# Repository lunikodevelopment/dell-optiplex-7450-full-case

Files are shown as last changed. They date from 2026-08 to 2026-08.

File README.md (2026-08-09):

# Dell OptiPlex 7450 AIO Full Enclosure — V3.1 Clearance-First

> [!IMPORTANT]
> **AI-authorship disclosure:** This CAD project and its documentation were generated with **OpenAI ChatGPT (GPT-5.6 Sol)** from Dell specifications, user-supplied photographs, independent product photographs, and iterative requirements. The CAD source, exported geometry, QA scripts/results, and engineering recommendations are AI-generated. This is **not a certified engineering product** and has not been physically validated on every Dell OptiPlex 7450 AIO.

V3.1 is the **pre-purchase / clearance-first** revision. It intentionally gives up a small amount of cosmetic tightness to remove dependence on unpublished Dell dimensions while retaining the full enclosure concept, wall mounting, H2C compatibility, and efficient SLS/MJF production.

## What changed from V3

- Dell receiver reduced from **138 × 138 mm to 128 × 128 mm**.
- Receiver remains **10 mm structurally thick** with 6 mm Dell-side standoffs.
- VESA remains the official **100 × 100 mm M4** pattern.
- Steel wall-stud/keyhole pattern widened to **84 × 56 mm**.
- Bottom-center receiver opening widened to **56 mm** and extended to the edge so the stand latch/mechanism is not trapped behind a flat plate.
- Positive anti-lift geometry corrected: seated clearance is **1.0 mm**, with no block/ear intersection, while only 1 mm of lift is available before the lock stops motion versus 14 mm required to release the keyholes.
- Enclosure body clearance increased to **5 mm per side** (10 mm total X/Y).
- Rear/depth clearance increased to **8 mm** beyond Dell's maximum published chassis depth.
- Front retention overlap reduced to **2 mm** per edge.
- Central shell exclusion increased to **190 × 190 mm**.
- Side I/O, optical-drive/control, rear-port and top-exhaust regions remain broadly open instead of depending on guessed port coordinates.
- All H2C parts remain inside the conservative **300 × 315 × 315 mm** design envelope; largest generated H2C part is about **295.62 × 210.45 × 74.3 mm**.

## Published Dell basis

- Chassis: **575.24 × 392.90 × 63.50 mm maximum published depth**.
- VESA: **FDMI MIS-D 100 × 100 mm, M4**.
- Minimum wall clearance: **20 mm**.
- V3.1 nominal Dell-rear-to-wall distance: **52.3 mm**.
- V3.1 nominal printed-shell-to-wall clearance: **41.5 mm**.

## Photo-derived rear-bay cross-check

The supplied near-orthogonal rear photograph contains the same four VESA threaded centers whose spacing is independently published as 100 mm. Using that known spacing as an image scale gives an approximate visible stand bay of **145.5–149.3 mm wide** and about **150.9 mm high**.

This is not metrology-grade because of perspective and edge ambiguity, but it gives the 128 mm receiver roughly **8.7–10.7 mm lateral clearance per side** and roughly **11.5 mm top/bottom clearance** against the visible bay boundary. The new 56 mm open-bottom notch additionally avoids the prominent stand latch visible below the lower M4 pair.

Independent rear photographs and genuine Dell 7450VESA bracket photographs corroborate the same bay/latch/bracket arrangement, although no dimensioned engineering drawing of the exterior recess or usable M4 thread depth was found. See `ONLINE_SOURCE_NOTES.md` and `REVALIDATION_V3_1.md`.

## Repository layout

Current source/build files:

- `source_parts_v3_1/` — chunked canonical V3.1 CadQuery source used by CI.
- `build_v3_1.py` — reconstructs `CAD_SOURCE_make_v3_1.py` and builds the CAD.
- `CAD_SOURCE_make_v3_1.py` — generated complete source file after CI runs.
- `.github/workflows/generate-cad.yml` — automatically regenerates production files.

Generated production files are committed under `generated/`:

- `generated/sls_mjf/` — **2 rear halves + 2 front halves** for large-format SLS/MJF PA12.
- `generated/h2c/` — **4 rear quadrants + 4 front quadrants** for H2C-class FDM.
- `generated/universal/` — structural receiver, wall plate, anti-lift block and seam joiners.
- `generated/fit_checks/` — inexpensive validation templates/coupons.
- `generated/optional_metal/` — optional 2 mm receiver backer in STL/STEP/DXF form.
- `generated/case_reference_assembly.step` — enclosure reference assembly.
- `generated/wall_interface_entry.step` / `generated/wall_interface_seated.step` — wall-interface kinematic references.

## Manufacturing paths

### H2C / large-format FDM

Use the `generated/h2c/` set. The enclosure quadrants are sized to stay under a conservative 300 × 315 × 315 mm envelope. A single nozzle/material is sufficient. See `H2C_PRINT_PLAN.md`.

### SLS / MJF

Use the `generated/sls_mjf/` set for the lowest assembly count: two rear shell halves and two front-retainer halves. PA12 or comparable functional nylon is preferred. See `SLS_MJF_PLAN.md`.

## Structural system

The printed enclosure is deliberately **not the primary wall-load path**. The Dell's VESA connection transfers through the 128 × 128 × 10 mm receiver to four steel M8 studs and the wall plate.

The receiver includes:

- 100 × 100 mm M4 Dell interface;
- approximately 20 mm OD fender-washer bearing areas;
- 84 × 56 mm four-stud pattern;
- 14 mm gravity seating travel;
- broad open-bottom latch relief;
- removable positive anti-lift block secured by an M5 fastener.

For a permanent installation, the optional 2 mm metal receiver backer or a commercial metal VESA backbone is strongly preferred.

## Fit checks

The design is intentionally much less dependent on unpublished Dell geometry, but the repository still includes cheap validation parts:

1. `generated/fit_checks/vesa_recess_fit_template_2p5mm.stl`
2. `generated/fit_checks/m8_keyhole_and_insert_coupon.stl`
3. `generated/fit_checks/enclosure_corner_depth_coupon.stl`
4. `generated/fit_checks/enclosure_front_corner_coupon.stl`
5. `generated/fit_checks/front_overlap_1_2_3mm_coupon.stl`
6. `generated/fit_checks/wall_drill_template_2mm.stl`

The **M4 screw length / usable thread depth remains unpublished**. Do not choose final screw length solely from this model.

## QA status

See `QA_RESULTS.json` and `REVALIDATION_V3_1.md`.

Current generated V3.1 checks include:

- receiver outline ≤140 mm: PASS;
- structural receiver thickness 9–10 mm: PASS;
- nominal shell-to-wall clearance ≥20 mm: PASS;
- wall/receiver collision in seated state: **0 mm³**;
- wall/receiver collision in entry state: **0 mm³**;
- positive lock collision-free when seated: PASS;
- lock prevents lift-off before 14 mm keyhole release travel: PASS;
- all exported STL meshes watertight: PASS;
- all H2C production parts inside the conservative envelope: PASS.

These are CAD/mesh checks, not certification of wall substrate, fasteners, printed-material strength, creep life, thermal behavior, or manufacturing variation in a used AIO.

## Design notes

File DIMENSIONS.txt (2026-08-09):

Dell OptiPlex 7450 AIO V3.1 design basis

Published Dell chassis envelope used: 575.24 x 392.90 x 63.50 mm max depth
Published VESA pattern: 100 x 100 mm, M4
Published minimum wall clearance: 20 mm

V3.1 receiver: 128 x 128 mm, 10 mm structural thickness + 6 mm Dell-side standoffs
M8 stud pattern: 84 x 56 mm
Keyhole seating travel: 14 mm
Central shell exclusion: 190 x 190 mm
Nominal internal X/Y clearance: 10 mm total (5 mm each side)
Extra depth clearance: 8 mm
Front overlap: 2 mm
Enclosure outer reference envelope: 591.24 x 408.90 x 74.30 mm
Nominal Dell rear to wall: 52.3 mm
Nominal shell to wall: 41.5 mm
H2C conservative part envelope: 300 x 315 x 315 mm
Largest H2C part: 295.62 x 210.45 x 74.30 mm

Approximate photo-derived visible stand bay: 145.5–149.3 mm wide x ~150.9 mm high. This is a photographic cross-check, not a dimensioned Dell specification.

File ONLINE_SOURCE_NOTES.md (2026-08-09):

# Online source notes — V3.1

Sources used to establish the design basis and cross-check the clearance-first revision:

1. **Dell OptiPlex 7450 AIO Owner's Manual — VESA wall mount**: confirms 100 × 100 mm VESA, M4 screws and a minimum 20 mm wall clearance.
2. **Dell OptiPlex 7450 AIO Owner's Manual — physical specifications**: confirms 575.24 mm width, 392.90 mm height, 63.5 mm non-touch depth / 62.79 mm touch depth.
3. **Dell OptiPlex 7450 AIO visual guide / service documentation**: confirms stand removal and the general external I/O, control and ventilation regions.
4. **Independent used-system rear photographs**: corroborate the square recessed stand bay and bottom-center latch arrangement after the stand is removed.
5. **Genuine Dell 7450VESA replacement-bracket photographs**: corroborate the internal VESA bracket arrangement.
6. **Bambu Lab H2C product documentation**: used only as an external printer-size cross-check; V3.1 nevertheless constrains its H2C parts to a conservative 300 × 315 × 315 mm design envelope.

No online source located during the V3.1 research provided a dimensioned engineering drawing of the exterior stand recess, exact rear curvature, or usable M4 thread depth. The receiver was therefore reduced to 128 × 128 mm, given an open-bottom latch relief, and combined with larger enclosure clearances so those unpublished dimensions are not required for nominal fit.

The photo-derived rear-bay figures in the README and revalidation report use the independently known 100 mm VESA spacing as an image scale. They are corroborative estimates rather than factory tolerances.

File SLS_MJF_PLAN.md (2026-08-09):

# SLS / MJF Plan — V3.1

Preferred material: **PA12 or comparable functional nylon**.

Production set:
- rear_left_half
- rear_right_half
- front_left_half
- front_right_half
- universal receiver/wall hardware as separate parts

The shell is thin-wall/open-frame geometry intended to avoid unnecessary solid material. Powder-bed production removes FDM support constraints. The service must confirm that the full-height half-shell parts fit its machine envelope and quotation rules.

For permanent wall mounting, keep the printed shell nonstructural and use the optional metal backer or a commercial metal VESA backbone.

The production set is generated under `generated/sls_mjf/` by the repository workflow.

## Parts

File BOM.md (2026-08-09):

# V3.1 hardware BOM

Structural interface:
- 4 × M4 Dell VESA screws — usable thread depth / final screw length remains unit-specific
- 4 × M4 fender washers, about 20 mm OD
- 4 × M8 steel carriage bolts / equivalent studs
- 4 × M8 large washers
- 4 × M8 locking nuts / thin jam nuts as required by the actual stud-head stack
- 1 × M5 socket-head screw for the positive anti-lift block
- 1 × M5 square nut for the receiver pocket
- optional 2 mm aluminum receiver backer
- optional secondary steel tether

Enclosure:
- M3 screws, washers and nyloc nuts for rear seam joiners
- 8 × M3 threaded inserts (or service-selected equivalent) for front retainer tabs
- 8 × M3 front-retainer screws

Wall:
- fasteners/anchors selected for the actual wall substrate; the CAD defines hole layout, not substrate-specific anchor selection.

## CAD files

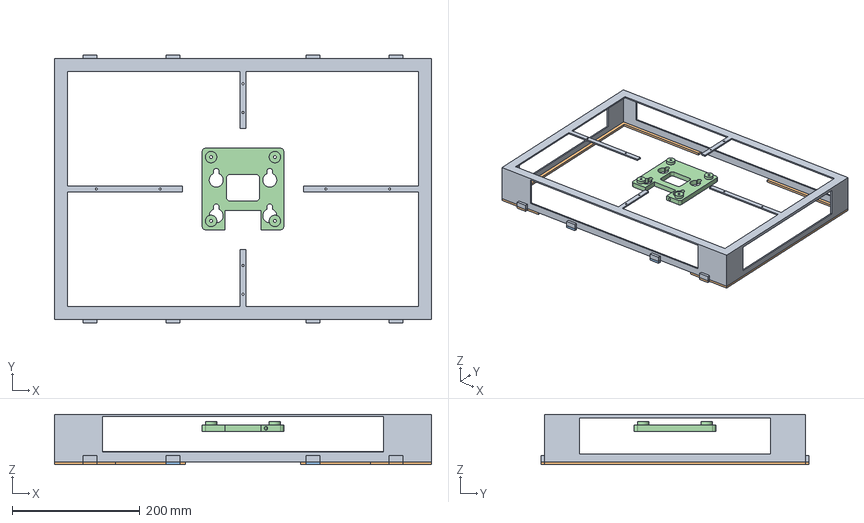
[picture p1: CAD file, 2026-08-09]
generated/case_reference_assembly.step
591.2 x 420.9 x 78.8 mm
rear_shell
front_retainer
vesa_receiver_reference

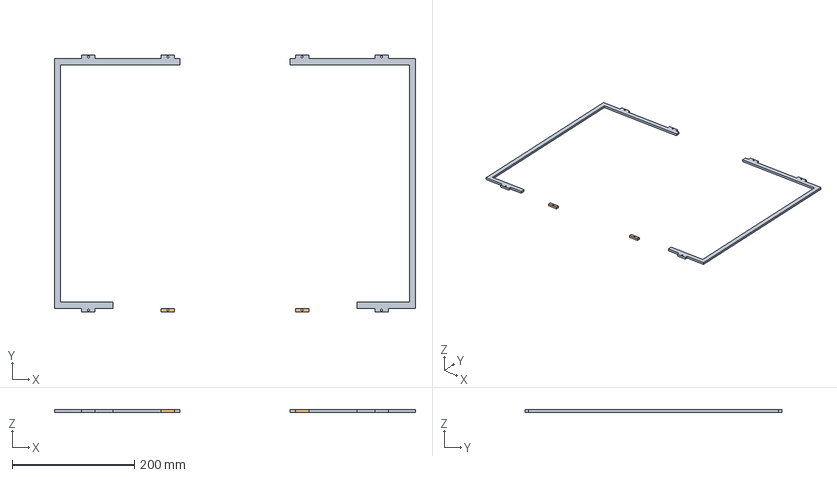
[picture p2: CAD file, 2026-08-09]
generated/universal/full_front_retainer_reference.step
591.2 x 420.9 x 4.50 mm

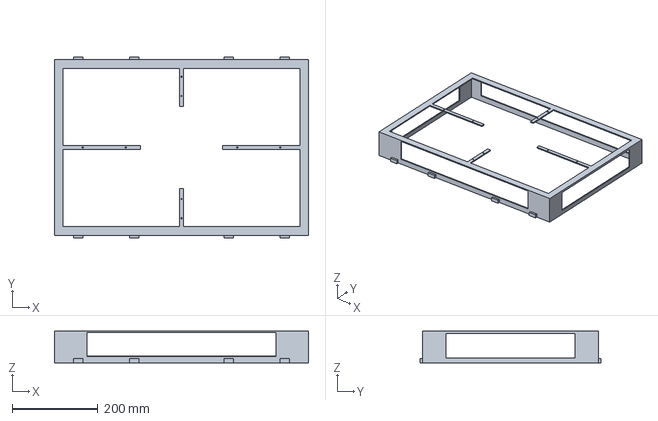
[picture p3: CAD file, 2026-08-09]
generated/universal/full_rear_shell_reference.step
591.2 x 420.9 x 74.3 mm

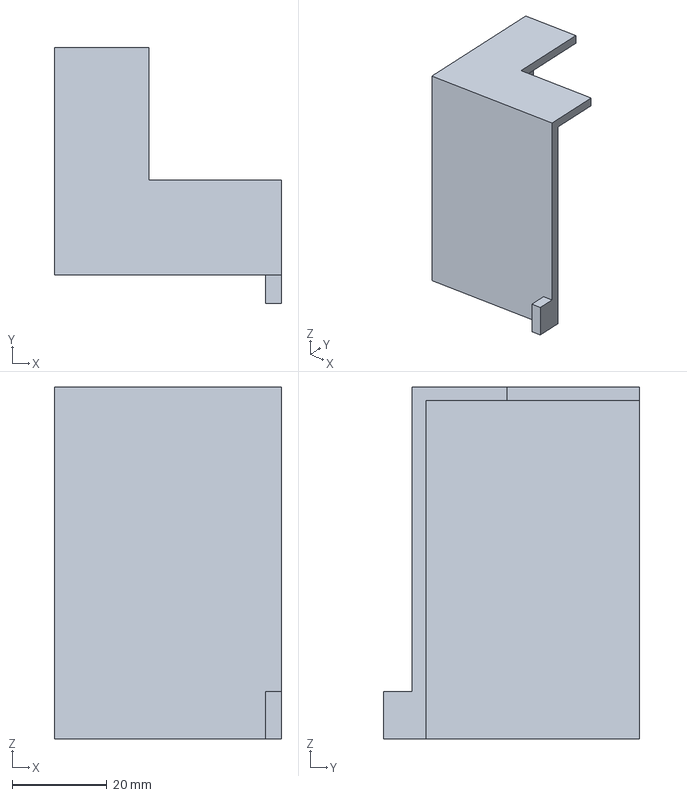
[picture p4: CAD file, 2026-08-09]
generated/fit_checks/enclosure_corner_depth_coupon.step
48.0 x 54.0 x 74.3 mm

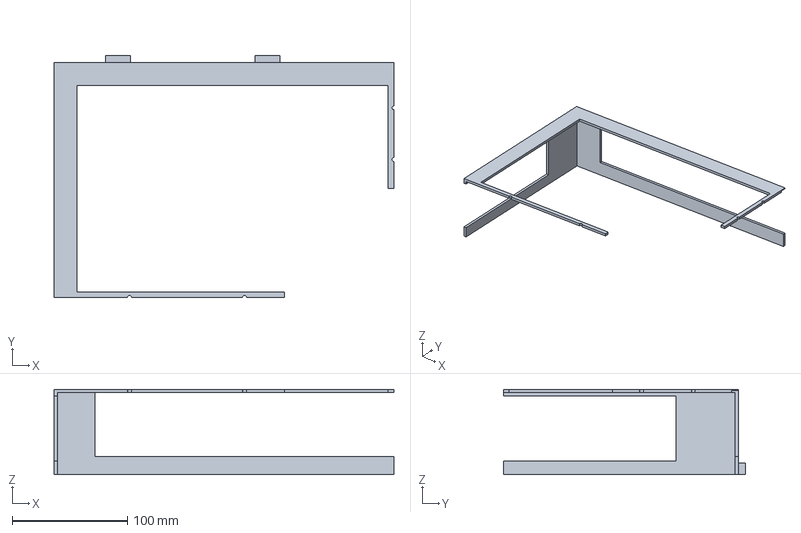
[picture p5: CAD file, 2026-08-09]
generated/h2c/rear_top_left.step
295.6 x 210.4 x 74.3 mm

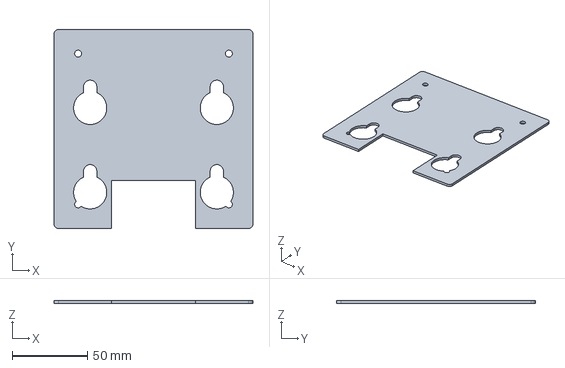
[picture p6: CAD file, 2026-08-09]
generated/optional_metal/optional_2mm_receiver_backer.step
132.0 x 132.0 x 2.00 mm

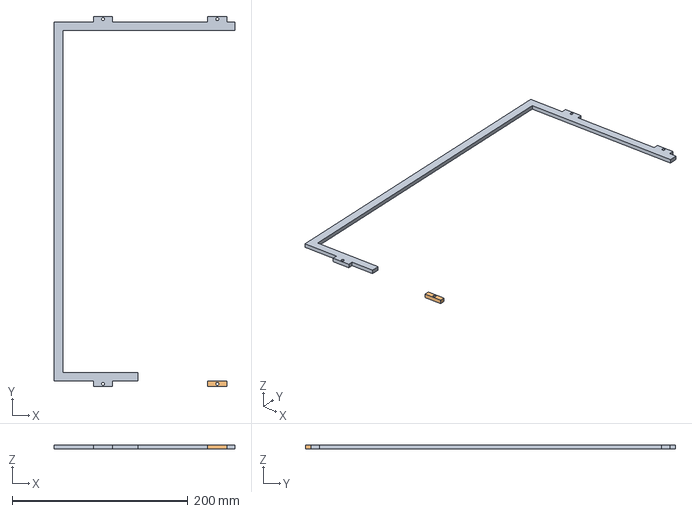
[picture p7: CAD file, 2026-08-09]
generated/sls_mjf/front_left_half.step
205.6 x 420.9 x 4.50 mm

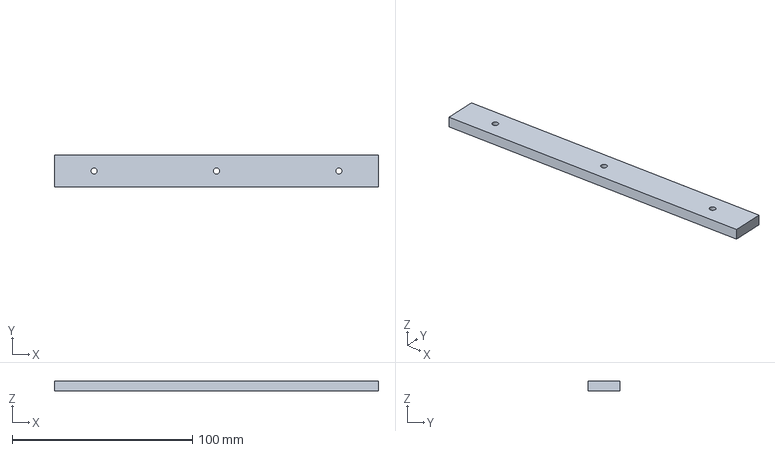
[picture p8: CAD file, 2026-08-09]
generated/universal/seam_joiner_180mm.step
180.0 x 18.0 x 5.50 mm

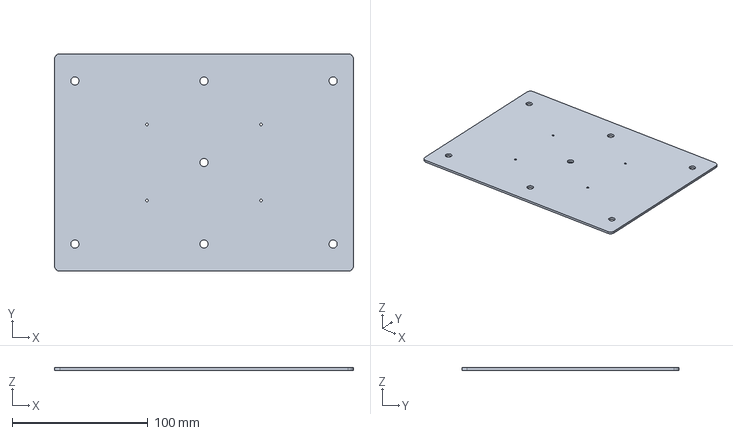
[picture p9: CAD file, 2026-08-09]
generated/fit_checks/wall_drill_template_2mm.step
220.0 x 160.0 x 2.00 mm

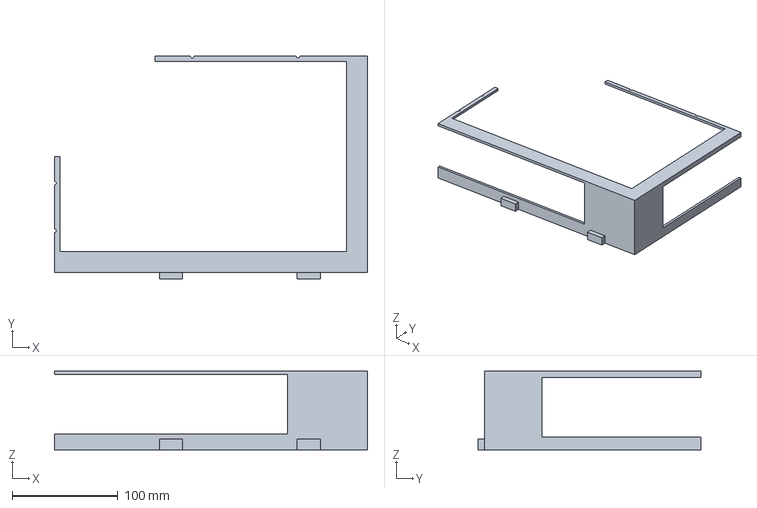
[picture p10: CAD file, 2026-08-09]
generated/h2c/rear_bottom_right.step
295.6 x 210.4 x 74.3 mm

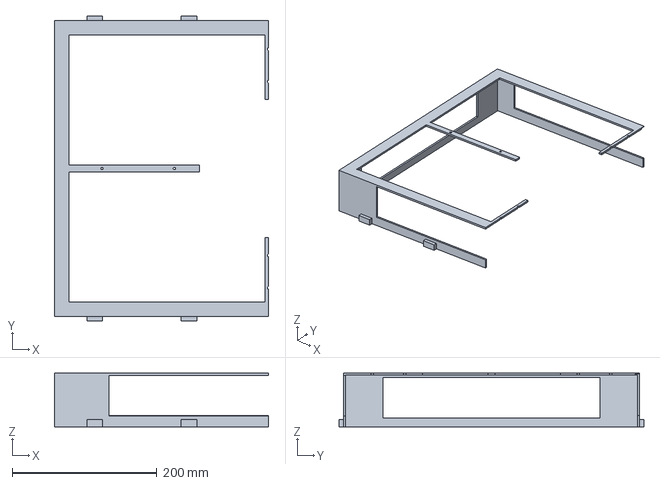
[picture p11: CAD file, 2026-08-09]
generated/sls_mjf/rear_left_half.step
295.6 x 420.9 x 74.3 mm

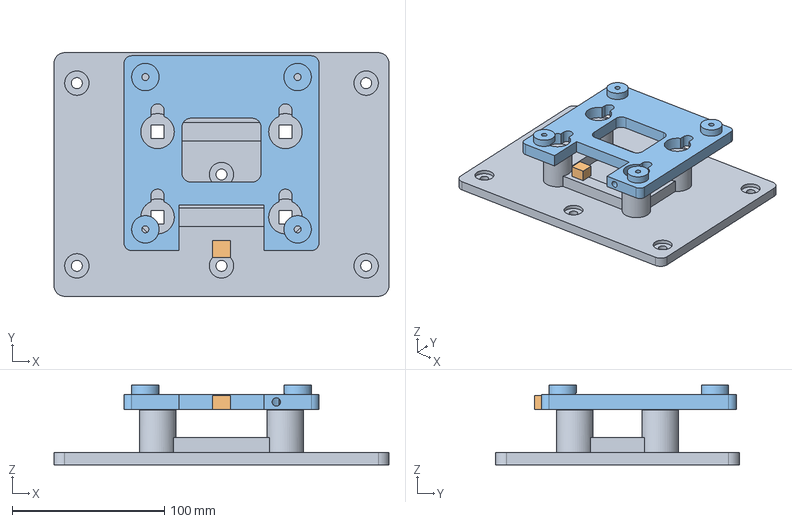
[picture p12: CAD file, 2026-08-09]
generated/wall_interface_entry.step
220.0 x 160.0 x 52.3 mm
wall_plate
receiver_entry

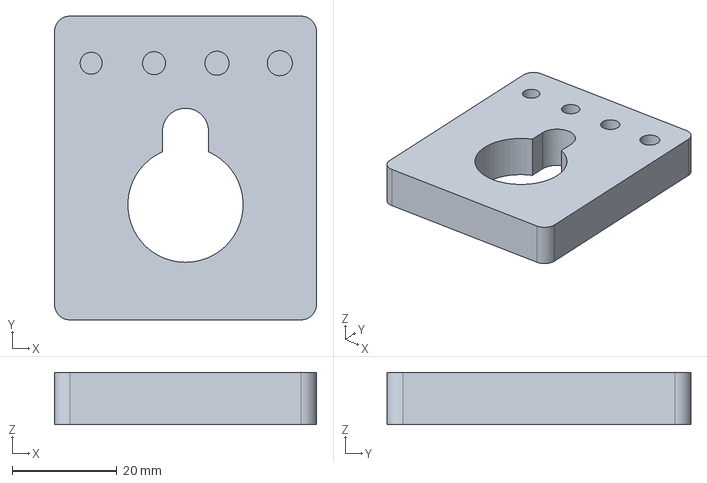
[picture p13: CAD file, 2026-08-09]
generated/fit_checks/m8_keyhole_and_insert_coupon.step
50.0 x 58.0 x 10.0 mm

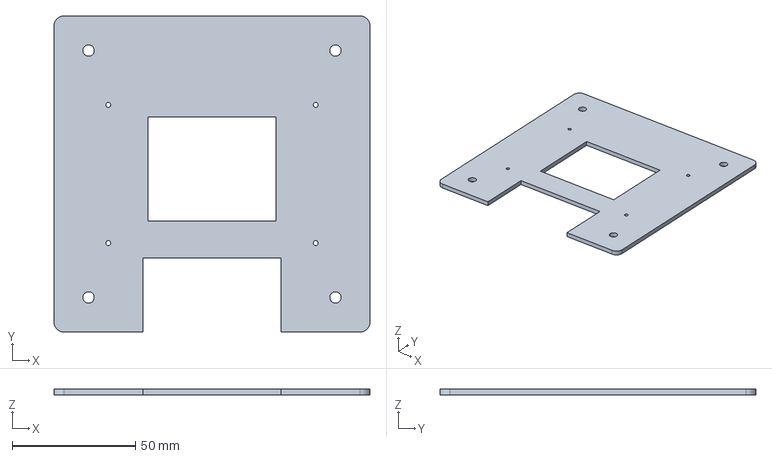
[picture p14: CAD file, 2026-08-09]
generated/fit_checks/vesa_recess_fit_template_2p5mm.step
128.0 x 128.0 x 2.50 mm

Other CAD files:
generated/h2c/rear_bottom_left.step
generated/sls_mjf/rear_right_half.step
generated/wall_interface_seated.step
generated/h2c/front_bottom_left.step
generated/fit_checks/enclosure_corner_depth_coupon.stl
generated/fit_checks/enclosure_front_corner_coupon.step
generated/fit_checks/enclosure_front_corner_coupon.stl
generated/fit_checks/front_overlap_1_2_3mm_coupon.step
generated/fit_checks/front_overlap_1_2_3mm_coupon.stl
generated/fit_checks/front_overlap_3_4_5mm_coupon.step
generated/fit_checks/m8_keyhole_and_insert_coupon.stl
generated/fit_checks/vesa_recess_fit_template_2p5mm.stl
generated/fit_checks/wall_drill_template_2mm.stl
generated/h2c/front_bottom_left.stl
generated/h2c/front_bottom_right.step
generated/h2c/front_bottom_right.stl
generated/h2c/front_top_left.step
generated/h2c/front_top_left.stl
generated/h2c/front_top_right.step
generated/h2c/front_top_right.stl
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

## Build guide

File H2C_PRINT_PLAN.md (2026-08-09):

# H2C Print Plan — V3.1

Design envelope used for every H2C part: **300 × 315 × 315 mm**.

Largest generated H2C part: approximately **295.62 × 210.45 × 74.3 mm**.

Recommended service approach:
- Enclosure quadrants: ASA, ABS-GF/CF where appropriate, or another heat/creep-resistant engineering filament offered by the service.
- Receiver and wall plate: use the strongest creep-resistant material the service supports; prefer the optional metal receiver backer for a permanent wall installation.
- Single-material/single-nozzle printing is sufficient.
- Ask the service to confirm actual printable area for the selected H2C nozzle mode and whether a brim is counted outside the model envelope.

Parts:
- rear_top_left
- rear_top_right
- rear_bottom_left
- rear_bottom_right
- front_top_left
- front_top_right
- front_bottom_left
- front_bottom_right

The H2C set is generated under `generated/h2c/` by the repository workflow.

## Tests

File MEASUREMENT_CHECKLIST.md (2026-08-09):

# V3.1 optional physical verification checklist

V3.1 is intentionally designed to reduce dependence on unpublished Dell dimensions. These checks are still useful if the AIO is available before ordering a final production enclosure:

- center-to-center VESA spacing (published expectation: 100 × 100 mm);
- usable M4 thread depth and final screw length;
- stand/VESA recess maximum width and height;
- recess depth from surrounding rear cover to the threaded inserts;
- latch protrusion and movement envelope;
- maximum rear curvature/depth at center and corners;
- left-side port-region limits;
- right-side optical-drive and OSD/power-region limits;
- distance from chassis outer edge to active display on all four sides;
- top exhaust start/end and slot width;
- bottom speaker/opening location;
- operating temperature around the top exhaust and wall gap during sustained load.

The clearance-first geometry does not require these values for its nominal published-dimension fit, but the included fit coupons remain the lowest-cost way to catch unusual unit condition, casing deformation, or screw-depth differences before paying for a full enclosure.

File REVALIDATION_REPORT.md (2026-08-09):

# V3.1 Revalidation Report

V3.1 replaces the previous receiver geometry with a clearance-first layout based on published Dell dimensions plus photographic cross-checking.

## Confirmed online

- Dell external envelope: **575.24 × 392.90 × max 63.50 mm**.
- VESA: **100 × 100 mm, M4**.
- Dell minimum wall clearance: **20 mm**.
- The removable stand exposes the central stand/VESA bay.
- Rear, side and top I/O/vent/control regions correspond with the broad openings used by this enclosure.

## Not published as dimensioned drawings

- exact stand-recess width/height/depth;
- exact rear curvature;
- exact latch protrusion;
- exact usable M4 thread depth;
- exact port coordinates and active-display edge offsets.

## V3.1 changes that reduce dependence on those unknowns

- receiver reduced to **128 × 128 mm**;
- **56 mm open-bottom notch** around the latch region;
- **6 mm Dell-side standoffs** around the M4 points;
- **5 mm clearance per X/Y side** and **8 mm extra depth clearance**;
- front overlap reduced to **2 mm**;
- **190 × 190 mm** central shell exclusion area;
- side, rear and top service/vent regions kept broadly open.

## Photo-derived cross-check

Using the known 100 mm VESA spacing in the supplied near-orthogonal rear photograph as an image scale gives an approximate visible bay width of **145.5–149.3 mm** and height of about **150.9 mm**. A 128 mm receiver therefore has roughly **8.7–10.7 mm lateral clearance per side** and about **11.5 mm vertical clearance per side** against the visible bay boundary. These are photographic estimates rather than metrology-grade dimensions.

## CAD/mesh QA

- receiver envelope ≤140 mm: PASS;
- 10 mm structural receiver thickness: PASS;
- nominal Dell-rear-to-wall distance: **52.3 mm**;
- nominal printed-shell-to-wall clearance: **41.5 mm**;
- wall/receiver intersection in seated state: **0 mm³**;
- wall/receiver intersection in entry state: **0 mm³**;
- anti-lift block seated gap: **1.0 mm**;
- keyhole release travel: **14 mm**;
- all exported STL meshes watertight: PASS;
- H2C conservative envelope: PASS;
- largest H2C part: **295.62 × 210.45 × 74.3 mm**.

The remaining unknowns are individual-unit manufacturing condition and usable M4 thread depth. The design minimizes dependence on them, but those values are not available from a published Dell dimensioned drawing.

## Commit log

2026-08-09 Add V3 hardware BOM
2026-08-09 Add V3 CAD QA results
2026-08-09 Add V3 CAD source part 1
2026-08-09 Add V3 CAD source part 2
2026-08-09 Add V3 CAD source part 3
2026-08-09 Add V3 CAD source part 4
2026-08-09 Add V3 CAD source QA part
2026-08-09 Add portable V3 CAD build script
2026-08-09 Add CAD build dependencies
2026-08-09 Add automatic CAD output generation workflow
2026-08-09 Generate V3 CAD outputs
    [case_reference_assembly.step, enclosure_corner_depth_coupon.step, enclosure_corner_depth_coupon.stl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]
2026-08-09 Document generated CAD files and keep explicit AI disclosure
2026-08-09 Publish V3.1 clearance-first enclosure
    Update CAD, QA, fit clearances, H2C/SLS-MJF plans and documentation to V3.1.
2026-08-09 Trigger V3.1 CAD regeneration
2026-08-09 Generate V3.1 clearance-first CAD outputs
    [case_reference_assembly.step, enclosure_corner_depth_coupon.step, enclosure_corner_depth_coupon.stl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]
2026-08-09 Upload generated V3.1 CAD as workflow artifact
